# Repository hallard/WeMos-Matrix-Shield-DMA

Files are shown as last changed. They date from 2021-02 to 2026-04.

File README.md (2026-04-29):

# ESP32 D1 Mini D1 RGB Matrix Shield 

This shield is the following of this [project](https://github.com/hallard/WeMos-Matrix-Shield) but I created a new repo since the board is different, wiring also and even the library used to drive Matrix.

This board is used to simplify ESP32 connectivity with a nice matric RGB led. This idea came from excellent project called [Morphing Digital Clock][3] done by [HariFun][1] Instructable. But with this library and current code I got some issues with mutitasking, and using same time the awesome Async libraries ([Web Server](https://github.com/me-no-dev/ESPAsyncWebServer) and [MQTT](https://github.com/marvinroger/async-mqtt-client)) getting very ofther in reboot and board reset. I don't blame anyone, the library used was just to drive matrix, it's always complicated mixing some libraries sometimes especially ones with hardware intensive related suff, IRQ's and TCP.

This was until [@mrfaptastic](https://github.com/mrfaptastic/ESP32-HUB75-MatrixPanel-I2S-DMA) released the DMA version wich is far less CPU intensive. I tested this one with Async Web Server, Async MQTT and OTA without any issue. You can participate to the @vortigont started discussion [here](https://github.com/mrfaptastic/ESP32-HUB75-MatrixPanel-I2S-DMA/discussions/96) Thanks to github for this new feature.

See it in action, nice isn't it?



This breakout has just few minimal features.

**New in Version V1.9**

- Touchpad 9 (T9) used and wired to GPIO32
- Exposed (top right corner) GPIO0 instead of GPIO32
- Reversed I2C connector order, because all I2C wiring have components on top except Luminosity TSL2561 BH1750, now fixed
- I2C connector order have drilled holes to match sensor plug, no need to solder to fix or swap sensor type. Just press it to fit into holes
- Added another pin close to I2C connector connected to GPIO34 (for using sensor IRQ pin for example)
- Major re-routing to fix issues

**New in Version V1.8a**

- **this PCB version does not work, please don't use it**
- Added C1, C2, C3 footprints. It's to add capacitor to poor 3.3V VOut of esp32 on board regulator. This one is not output filtered enough resulting sometimes with brownout reset loop. Now you can plug radial or 1 (or 2) SMD 0805 in parallel

**New in DMA Version V1.8**

- **this PCB version does not work, please don't use it**
- Removed ESP8266 compatibility, since DMA need more GPIO it's now exclusive to ESP32 boards with WeMos Mini D1 wiring called ESP32 Mini Kit or ESP32 Wemos, or ESP32 MH-ET Live such as this [banggood model](https://www.banggood.com/Wemos-D1-Mini-ESP32-ESP-32-WiFiBluetooth-Internet-Of-Things-Development-Board-Based-ESP8266-p-1205854.html) or this [aliexpress](https://www.aliexpress.com/item/MH-ET-LIVE-D1-mini-ESP32-ESP-32-WiFi-Bluetooth-Internet-of-Things-development-board-based/32815530502.html). But you can find a lot also on ebay, not a problem.
- PCB board has been extented to fit this ESP32 Mini module .
- LDR to dynamically change brightness according to ambiant light
- I2C connectors as header and Groove to plug a bunch of sensors
- Added one touch pad button
- No need to wire back the shield to HUB75 output of the Matrix Panel

Please check wiring and picture before ordering, should looks like something like that:

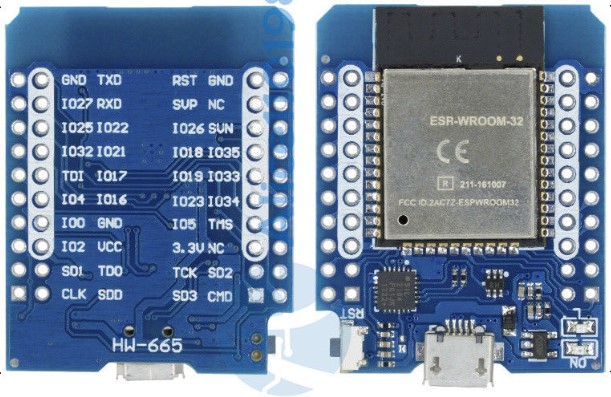
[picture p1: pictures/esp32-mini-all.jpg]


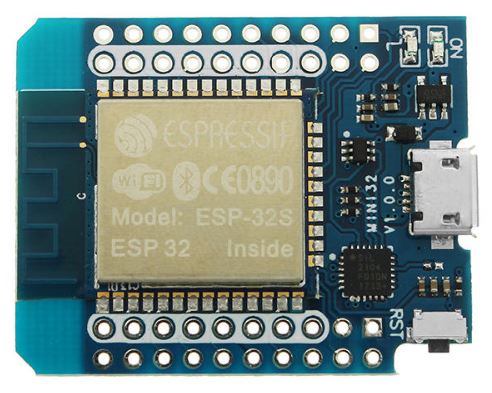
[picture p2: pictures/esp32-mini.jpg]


**V1.9 are fully tested and working**.

**V1.8 and V1.8a boards are not working** I've been too confident, this is the 1st time I need to throw out all boards. Reason is that both ESP32 headers the ones side by side were reversed (on each side).
I mean the 1st was the 2nd and vice versa), So as you can imagine nothing was unable to works, even flashing ESP32.

# Detailed Description

Look at the schematics for more informations.

# Schematic  

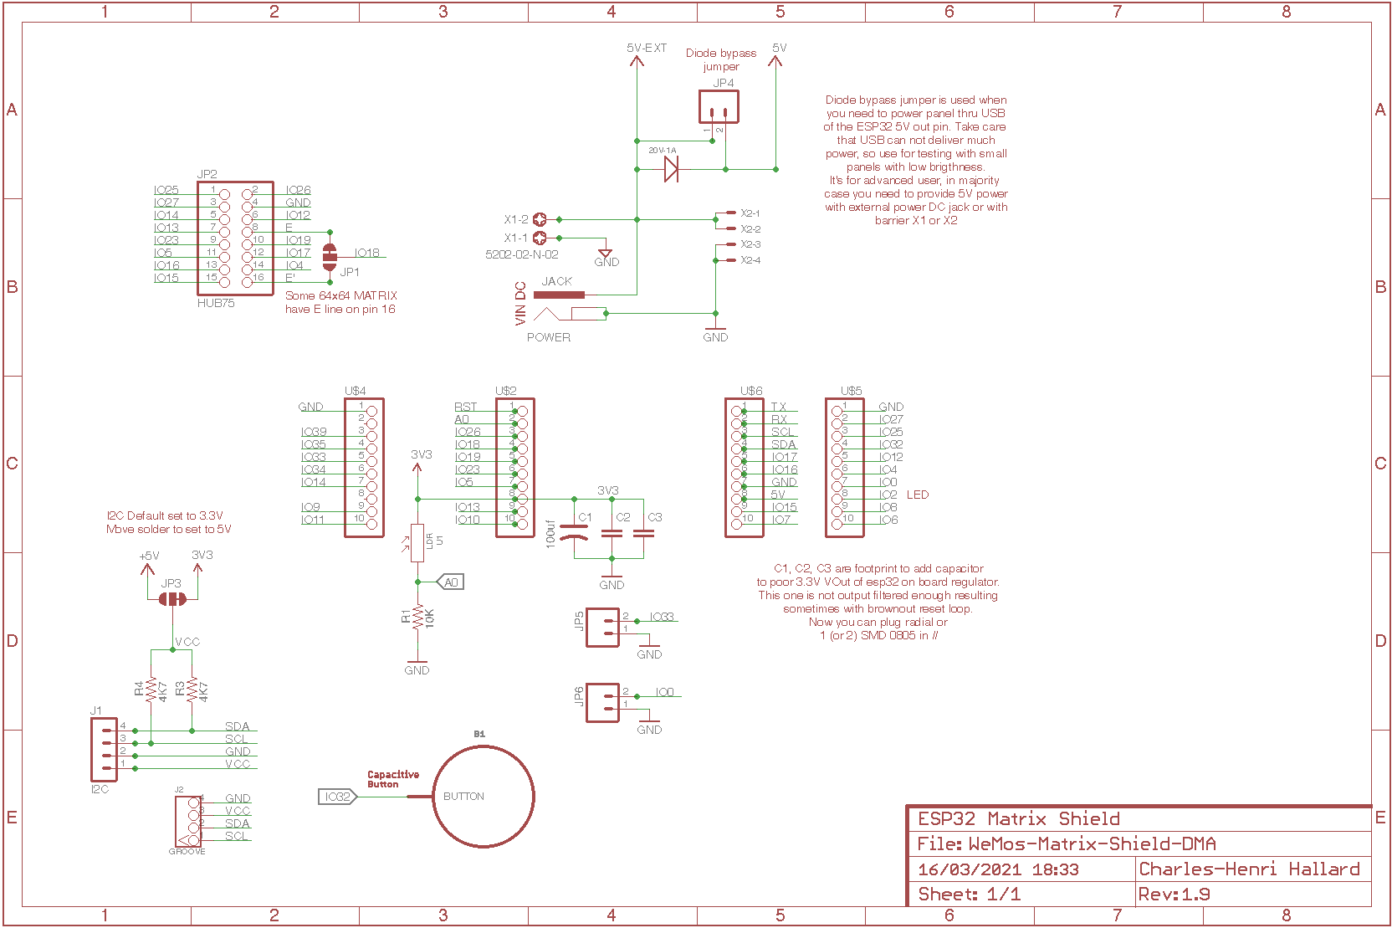
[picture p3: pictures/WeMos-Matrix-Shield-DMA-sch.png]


# Boards  

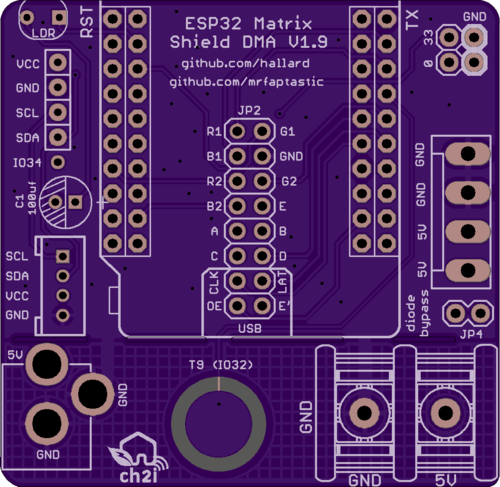
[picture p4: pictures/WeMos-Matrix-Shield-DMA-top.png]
Top
&nbsp;
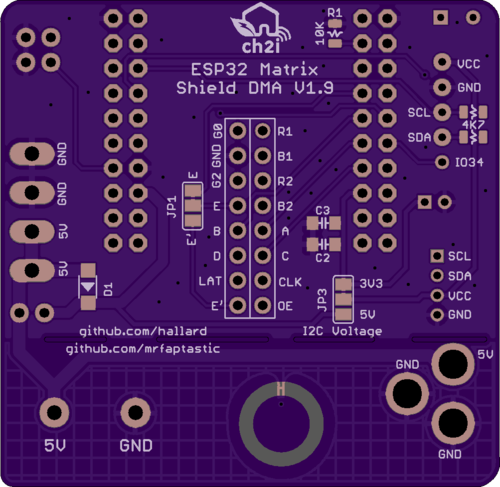
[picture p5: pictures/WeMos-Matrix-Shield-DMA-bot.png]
Bottom


~~You can order PCBs of this board at [PCBs.io)(ttps://www.pcbs.io/)~~

 ~~PCBs.io give me some reward when you order my designed boards from their site. This is pretty good, because I can use these rewards to create and design new boards and order boards for a discounted price, so if you don't care about PCB manufacturer please use PCBs.io.~~

Looks like PCBs.io is gone, I do not have any rewards from PCBs.io since August 2020 and my free order placed after are still not received, so my guess they are not on business anymore and my $1000 rewards are not usable anymore, too bad.

So you can order the board on [oshpark](https://oshpark.com) or submit gerbers.zip file to any PCB manufacturer of your choice.

- [V1.9](https://oshpark.com/shared_projects/gCeBFgxd)

It's a pitty after several discuss with OSHPark that I can't have any rewards for each people ordering my boards, this would allow me to order free PCB for shared projects and create new ones. For information my shared boards generated a total of **$285 162.00** orders at PCBs.io in 4 years, not bad at all :-)

Hoping one day OSHparks will thanks me giving them this market. 

# Firmware

I suggest you to look at the awesome [examples](https://github.com/mrfaptastic/ESP32-HUB75-MatrixPanel-I2S-DMA/tree/master/examplesk) located in the [library](https://github.com/mrfaptastic/ESP32-HUB75-MatrixPanel-I2S-DMA) driving the Matrix Panel.
 
# Assembled boards

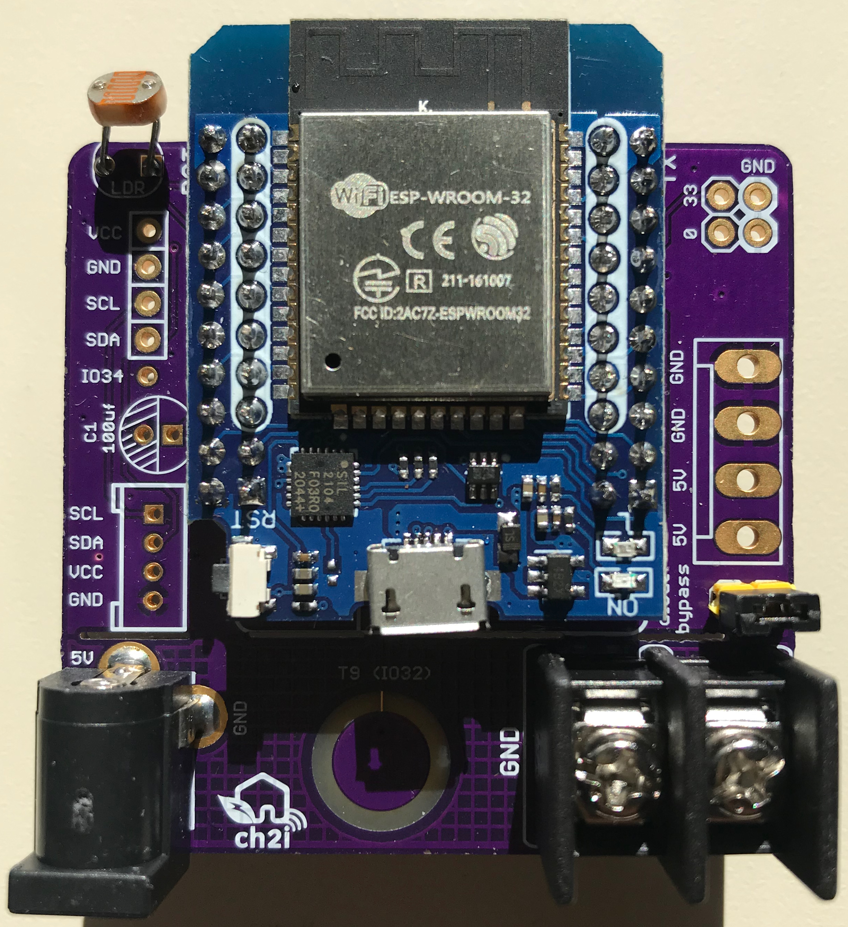
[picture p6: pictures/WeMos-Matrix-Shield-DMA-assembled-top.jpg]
Assembled Top
&nbsp;
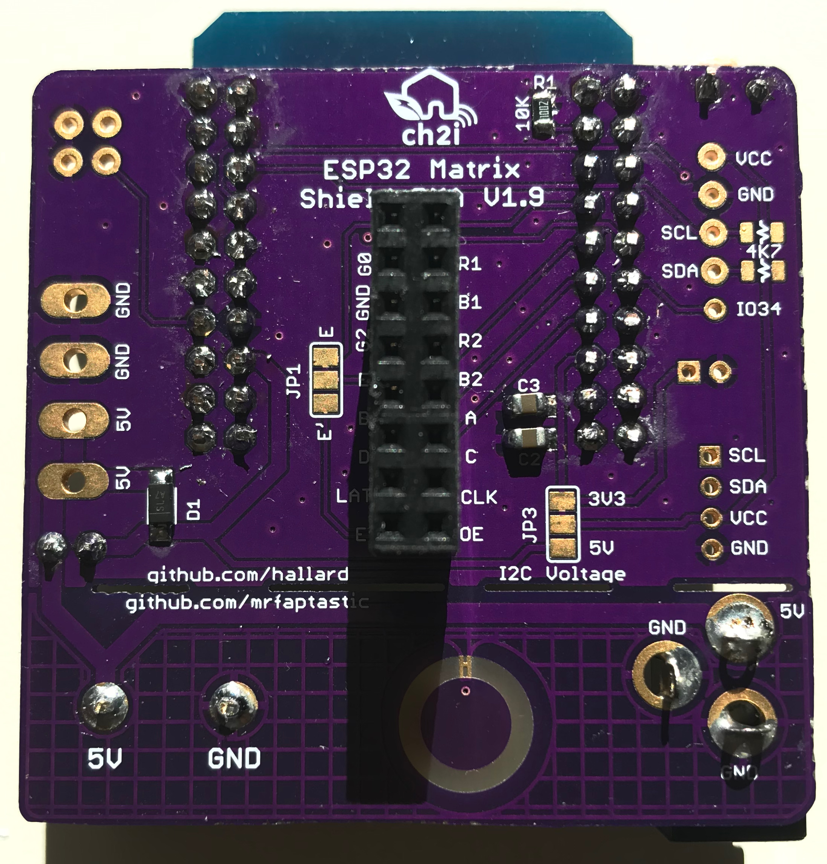
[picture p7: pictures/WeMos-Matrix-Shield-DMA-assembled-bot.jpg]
Assembled Bottom


# BOM

Nothing fancy, just some headers and 2 differents power conector (choose the one you prefer) :

 - 10K 0805 resistor for LDR
 - Any LDR PhotoCell 5528
 - I2C 4.7K resistor 0805 if needed, default I2C set to 3.3V use JP3 if you prefer 5V
 - For better stability C1 100uF 16V electrolytic, or C2 100uF 0805, or C2+C3 47uF 0805
 - Diode can be any Schottky diode barrier and is not mandatory (if not close JP4 jumper)
 - Ebay search for "DC Power Jack Barrel PCB Mount"
 - 7.62mm barrier terminal block [example](https://ebyelectro.com/terminal-block-product-info.asp?ProductID=333)
 - Ebay search for "2X8 Pin 2.54mm Double Row Female Header" or polulu product #1028, you can also use twice 1x8 pin female or even twice 2x4 pins female, plenty of option for this one
 
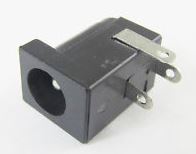
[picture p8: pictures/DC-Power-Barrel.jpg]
 
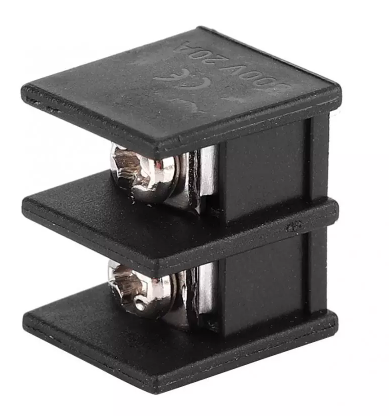
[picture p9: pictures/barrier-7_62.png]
 
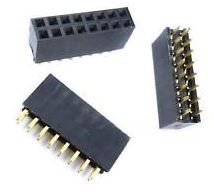
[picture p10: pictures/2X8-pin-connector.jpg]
 

# License

   

This work is licensed under a [Creative Commons Attribution-NonCommercial-ShareAlike 4.0 International License](https://creativecommons.org/licenses/by-nc-sa/4.0/)    

# Misc

See news and other projects on my [blog][2] 

Thanks to @mrfaptastic, @vortigont, @me-no-dev and all other I may forgot.
 
[1]: https://www.instructables.com/member/HariFun/
[2]: https://hallard.me
[3]: https://www.instructables.com/id/Morphing-Digital-Clock/
[4]: https://PCBs.io/share/

[20]: https://wiki.wemos.cc/products:d1:d1_mini_lite
[21]: https://wiki.wemos.cc/products:d1:d1_mini
[22]: https://wiki.wemos.cc/products:d1:d1_mini_pro

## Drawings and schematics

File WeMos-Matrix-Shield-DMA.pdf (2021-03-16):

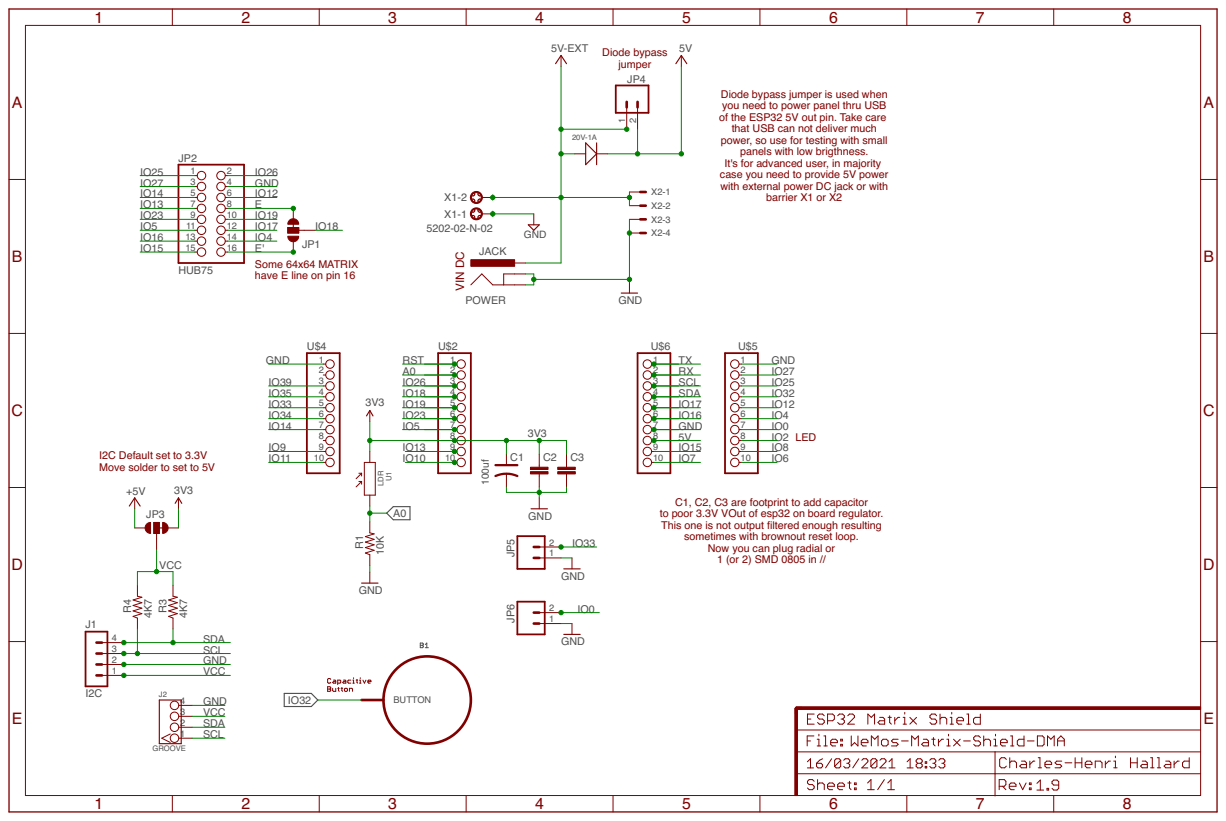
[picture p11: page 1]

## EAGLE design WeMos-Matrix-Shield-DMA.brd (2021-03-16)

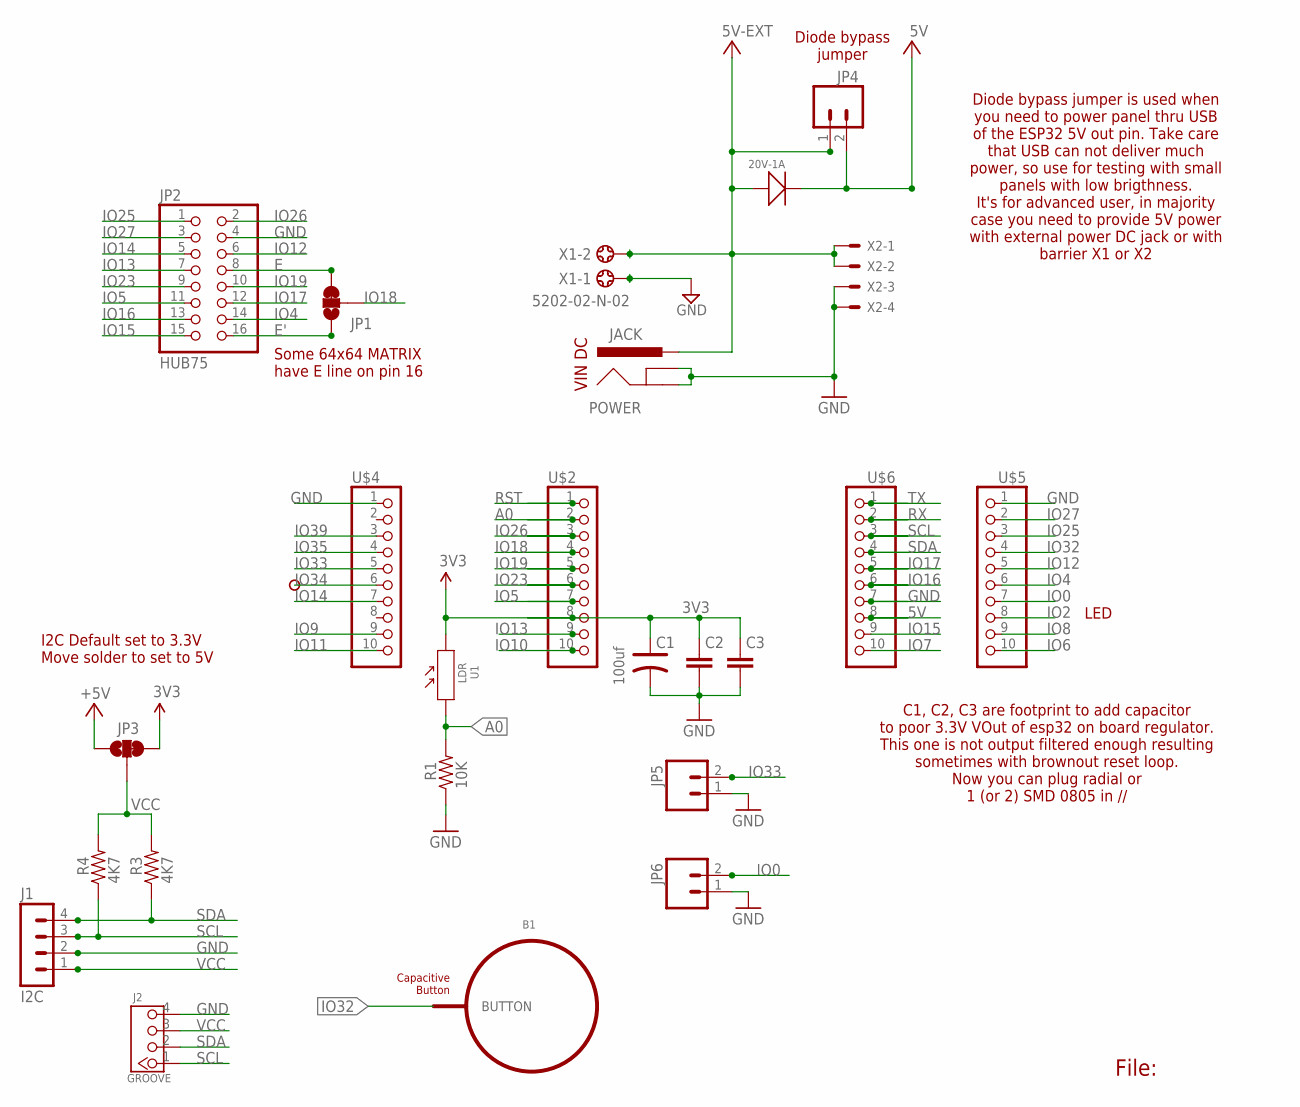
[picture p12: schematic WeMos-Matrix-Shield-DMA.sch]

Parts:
B1: BUTTON_PASSIVE6MM; BUTTON_PASSIVE_6MM
C1: 100uf; PC-D5.3MM
C2, C3: CAP0805-CAP-LARGEPADS; 0805-CAP-LARGEPADS
D3: 20V-1A; SOD-123
J1: I2C; 1X04_LOCK_HOLE
J2: GROOVE; 2.0_1X4
JACK: POWER; POWER_JACK_PTH
JP1, JP3: JUMPER-PAD-3-2OF3_NC_BY_TRACE_LARGE; PAD-JUMPER-3-2OF3_NC_BY_TRACE_YES_SILK_LARGE
JP2: HUB75; 2X08
JP4, JP5, JP6: M02; 1X02
P2: PADSMALL; PAD-SMALL
R1: 10K; 0805-RES
R3, R4: 4K7; 0805-RES
U1: LDR; SNR2-3.0
U$2, U$4, U$5, U$6: PINHD-1X10; 1X10-BIG
X1: 5202-02-N-02
X2: KK-156-4

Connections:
3V3: C1.+, C2.1, C3.1, JP3.3, U1.2, U$2.8
5V: D3.-, JP3.1, JP4.2, U$6.8
5V-EXT: D3.+, JACK.PWR, JP4.1, X1.2, X2.1, X2.2
A0: R1.2, U1.1, U$2.2
E: JP1.3, JP2.8
E': JP1.1, JP2.16
GND: C1.-, C2.2, C3.2, J1.2, J2.4, JACK.GND, JACK.GNDBREAK, JP2.4, JP5.1, JP6.1, R1.1, U$4.1, U$5.1, U$6.7, X1.1, X2.3, X2.4
IO0: JP6.2, U$5.7
IO2: U$5.8
IO4: JP2.14, U$5.6
IO5: JP2.11, U$2.7
IO6: U$5.10
IO7: U$6.10
IO8: U$5.9
IO9: U$4.9
IO10: U$2.10
IO11: U$4.10
IO12: JP2.6, U$5.5
IO13: JP2.7, U$2.9
IO14: JP2.5, U$4.7
IO15: JP2.15, U$6.9
IO16: JP2.13, U$6.6
IO17: JP2.12, U$6.5
IO18: JP1.2, U$2.4
IO19: JP2.10, U$2.5
IO23: JP2.9, U$2.6
IO25: JP2.1, U$5.3
IO26: JP2.2, U$2.3
IO27: JP2.3, U$5.2
IO32: B1.BUTTON, U$5.4
IO33: JP5.2, U$4.5
IO34: P2.1, U$4.6
IO35: U$4.4
IO39: U$4.3
RST: U$2.1
RX: U$6.2
SCL: J1.3, J2.1, R4.1, U$6.3
SDA: J1.4, J2.2, R3.1, U$6.4
TX: U$6.1
VCC: J1.1, J2.3, JP3.2, R3.2, R4.2

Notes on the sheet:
File:
VIN DC
I2C Default set to 3.3V Move solder to set to 5V
Some 64x64 MATRIX have E line on pin 16
Diode bypass jumper
Diode bypass jumper is used when you need to power panel thru USB of the ESP32 5V out pin. Take care that USB can not deliver much power, so use for testing with small panels with low brigthness. It's for advanced user, in majority case you need to provide 5V power with external power DC jack or wi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
C1, C2, C3 are footprint to add capacitor to poor 3.3V VOut of esp32 on board regulator. This one is not output filtered enough resulting sometimes with brownout reset loop. Now you can plug radial or 1 (or 2) SMD 0805 in //
LED

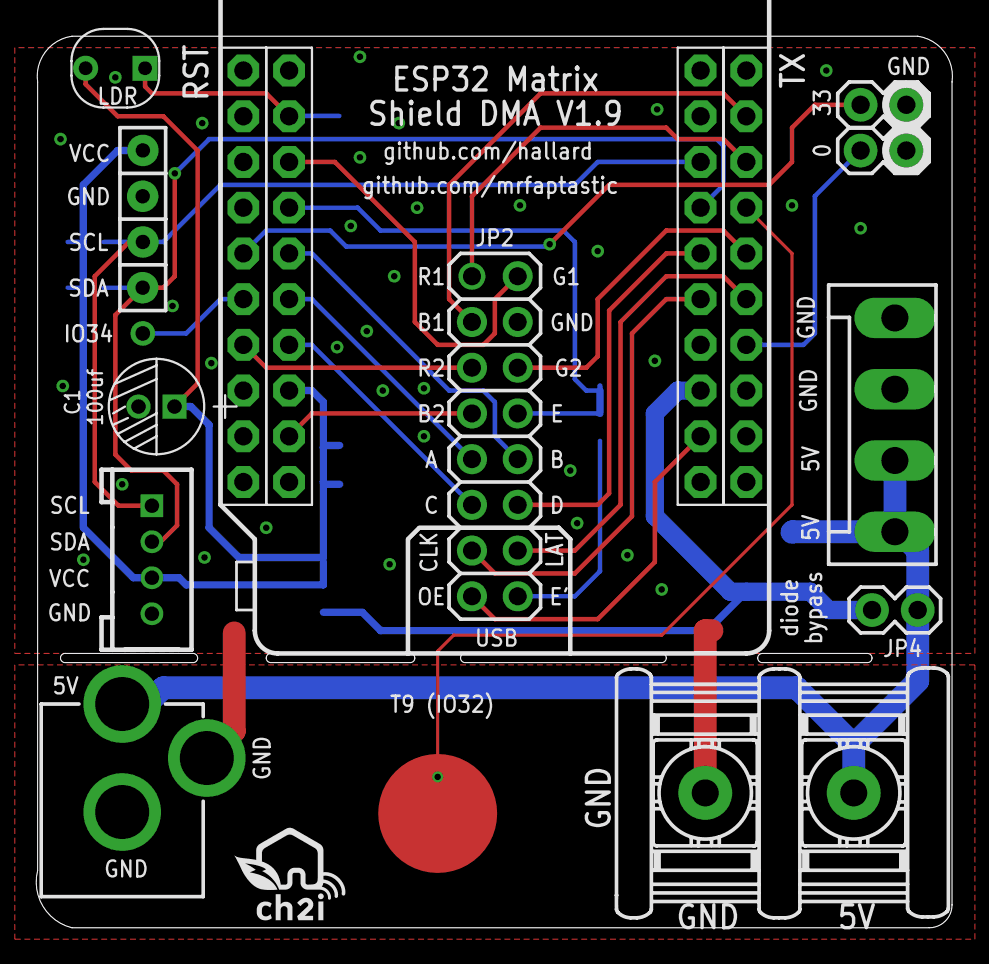
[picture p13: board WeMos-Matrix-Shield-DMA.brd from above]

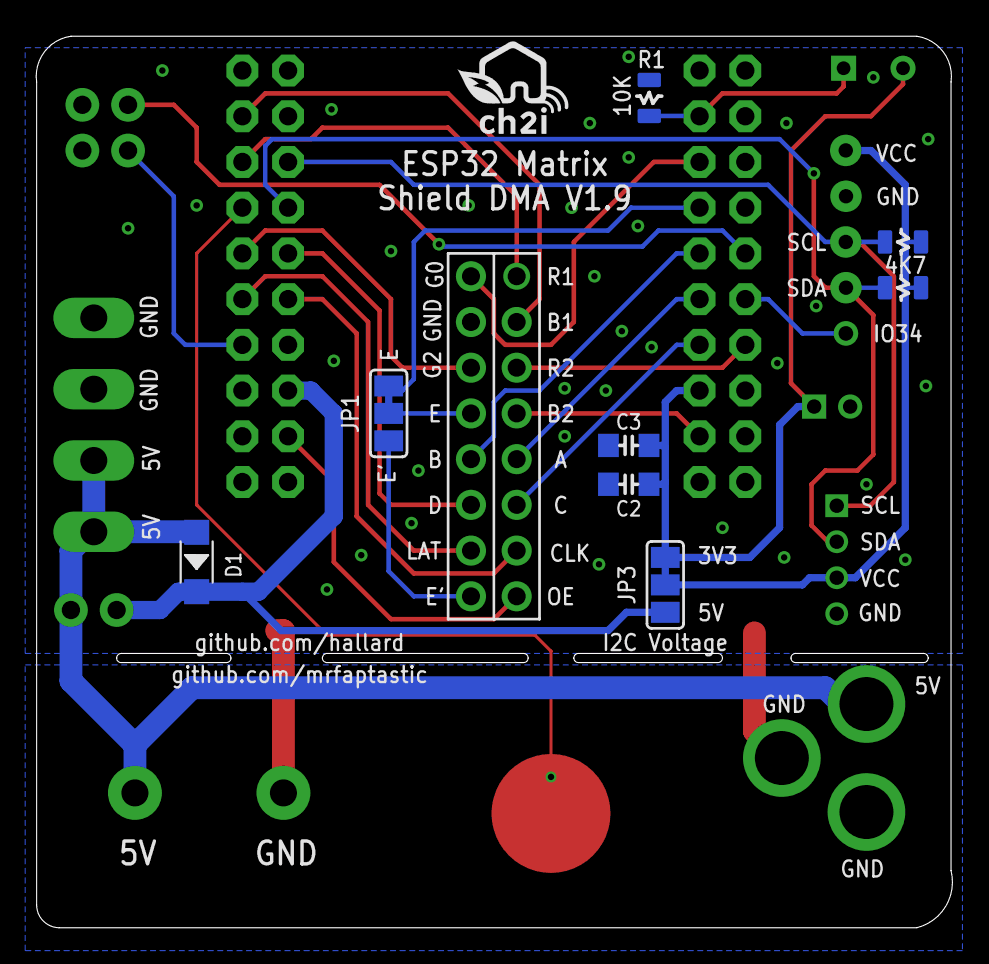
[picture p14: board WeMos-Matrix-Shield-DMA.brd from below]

Board: 2 copper layers, 50.9 x 49.5 mm, 27 parts (9 on the bottom side), 28 nets.

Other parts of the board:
U$7, U$8: LOGO_C2I_015

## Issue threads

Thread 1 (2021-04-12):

Small corrections, and a couple of questions

bogd, 2021-04-12:
First of all, thank you for the great work you did on this - it was the only open-source PCB that I could find for the I2S library! Your work is truly appreciated!!

A few (very small) things you may want to fix in the next version:
- the silkscreen on the back still shows a G0 (on the front it has G1 for the same pin)
- on the silkscreen, you have links to your and mrfaptastic's github pages - unfortunately, the links partly overlap with the cutouts in the board, so they can be difficult to read

Also, a couple of questions for you:
- what type of screw terminal are you using? Because the ones that I could source (such as [this one](https://www.aliexpress.com/item/4000600315390.html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,searchweb201602_,searchweb201603_) ) all have the pins offset from the center - while the footprint on your board has the pins fully centered
[ Edit - found them! Thanks to the link you posted, I managed to find them [here](https://www.aliexpress.com/item/32359125431.html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,searchweb201602_,searchweb201603_). They just seem to be a... rare breed, compared to the asymmetrical ones :) )
- what type of connector should I use for the 5V/GND connector on the side of the board? I originally assumed it would be something like [this](https://www.aliexpress.com/item/1005002157208121.html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,searchweb201602_,searchweb201603_), but it seems to have different pin spacing
[ Edit - found this one as well, by looking at the schematic. It is a KK-156-4 connector. I would guess [this one](https://eu.mouser.com/ProductDetail/Molex/76650-0102?qs=5NHWMpvrJ2C2NvuJzvI7ew%3D%3D)? ]
- did I understand the T9/IO32 pad correctly? Is it designed to work as a touch sensor? If so, can you tell us how  to read it from code?
[ Edit - found this one as well :) . The ESP32 has dedicated touch pins - T9 being "Touch 9". A nice tutorial on using them is [here](https://randomnerdtutorials.com/esp32-touch-pins-arduino-ide/)

So my questions have been answered - however, I will leave them here, in case you may want to add some additional info to the documentation for the board (such as the touchpin tutorial linked above)
].

Once again, a big _thank you_ for your work on this!!

hallard, 2021-08-15:
@bogd Nice you found your answers, sure sometimes link on aliexpress change and product also so it's complicated to keep them up to date.

Thank you for sharing your answer and links.

Have fun

bogd, 2021-08-16:
@hallard - thank you once again. I truly appreciate all the work you put into this, and the fact that you open sourced the project. In fact, your work gave me the courage to start building my own version of the matrix shield (and, of course, I open sourced that as well - share and share alike :) ).

I will close this issue now, since all my questions have been answered. Once again, a big thank you!!

Closed 2021-08-16.

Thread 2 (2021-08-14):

Source for boards

lanman1, 2021-08-14:
You can try using https://www.pcbway.com/   I have used them before, they are inexpensive and have a rewards system.  The quality is excellent and I usually get a free gift when I order boards.  10 boards are $15 shipped to the US.

Hope this helps and thank you for your work.

lanman1, 2021-08-14:
one thing I notice when I upload the Gerbers, it looks like pads and not thru-hole.
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

hallard, 2021-08-15:
That is strange, uploaded zip file to oshpark and looks nice

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

Anyway last time I tried pcbway for an already done board by someone else it told me I needed to wait until manual verification from pcbway team, so I gave up, may be need to try again.

lanman1, 2021-08-15:
Yeah, there usually i a manual verification where a human looks at it to make sure it is ok.  Usually takes less than a day.  I've ordered from them probably 10 times but maybe that aren't as good for EU.  I'll probably go ahead and place an order and report back, 10 boards through them are cheaper than the 3 for Oshpark.  I could be doing something wrong tho  :)

bogd, 2021-08-16:
@lanman1 - I used jlcpcb, and their system did show the drill holes correctly. And, indeed, when I received the boards, they did have the correct holes drilled.

I have also uploaded the current version of the gerbers.zip in this repo to their system, and once again it shows the drill holes correctly:
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

However, the exact same file viewed in pcbway's viewer does not show the drill holes:
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

It looks like a limitation of their gerbers viewer.... (and an ugly one, at that :) )

lanman1, 2021-08-18:
I'll give jlcpcb a shot, thanks!

vortigont, 2021-08-19:
I've got my batch from cnospcb and those are just fine. Thanks to @hallard for making his work public, it is much more comfortable to use shields than messing with dangling jump wires :)

M10CUBE, 2021-08-20:
Thanks @hallard for the grate V1.9 design. I got my lot of PCBs. Now trying to lit the RGB display but having problems with the display (16x32) found in my lab with the HUB75 connector. It has only A and B signal rows with C and grounded.
So I see confusing images. While I am waiting a new RGB from China is any example to guide me how to position text and display simple numbers or text? The examples do not have similar software.
The RGB will be used to display environmental data for our project
https://hackaday.io/project/171770-m10cube
Thanks a lot

EclipseBoom, 2023-03-29:
Here is a tip I swiped from SmartMatrix for Teensy.  If you use a 20-way female dual row connector for the panel and clip off the extra 2 pins on each side, the connector will fit snugly into the IDC cable plug on the panel with no chance to get the connector offset like it can with a 16-way.

Also, if you don't put female headers on the Wemos HUB75 board it is much lower profile and can almost fit within the plastic frames of the panel itself.  Just solder the ESP32 unit onto the HUB75 interface and clip off the extra long pins on one side.  Can't come loose that way either.

Finally I like to use the JST/Molex in a Right-Angle connector to supply 5V to the ESP32 HUB75 board.  This allows the typical 2-plug panel power cable to connect one to the panel and the second to the HUB board leaving the fork terminals for the power supply.  Nice and clean with no extra cables required for a single panel configuration.

Also not really an issue.  There is not really any way I can use the touch button and I don't need the LDR so those GPIO could be used for other things.  I would like to see the extra GPIO gathered into a header to connect remote buttons and controls and so forth away from behind the panel.

M10CUBE, 2023-03-30:
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
@EclipseBoom can you be specific on that? do you have pictures?
For mine (first image)  I choose to use long 2x20 socket for the HUB75 connector and for the ESP32 to sit on. I like to see yours but with images if you can find some time. That will help to integrate your ideas .

Now the P3-6432-21-16S-D1 RGB display I got is working fine (first image)
The problem is with a second P4 RGB display the S-P4-3020-A3 display (second image) I have and is not working. Just flashing in a strange way.
This is a similar one:
https://www.aliexpress.com/i/32514844235.html
It has the TC7258EN (8-channel LED display line scanning blanking control driver) and MBI5124 (16 Channel Constant Current LED Driver).
Any idea who to make that work? Is the same driver?
I will appreciate any ideas.
Thanks a lot in advance
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

EclipseBoom, 2023-03-30:
Here is my low-profile configuration.  I mount the panels to a 12mm high Aluminum channel and this fits under that.
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

M10CUBE, 2023-03-30:
Ok  I see your idea. Looks nice. Your panels must  be different than mine.
Thank you

Στις Πέμ, 30 Μαρ 2023, 20:05 ο χρήστης EclipseBoom ***@***.***>
έγραψε:

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

Yaxit, 2023-05-04:
@EclipseBoom could you point me to the connector you used for the screen power (white one with 2 5V and 2GND)? I cannot find the one I want :D

EclipseBoom, 2023-05-04:
That connector is JST-VH series.  S4P-VH(LF)(SN)  Bought at Digikey.

There is a Molex one that fits too but it has little nubs on the bottom of the plastic that need to be cut off and more expensive.

Yaxit, 2023-05-05:
Thank you. Would be nice to have it in the board BOM along the rest.

crazy-weasel, 2023-07-19:
Hi, I ordered a few v1.9 PCBs via jlcpcp and now I have more than I need. :)

If anyone needs some, I could send them to you. Shipping within the EU should be reasonable if you want only one or two (or three..)

glen020, 2024-02-25:
Hey, Got my pcb's working flawlessly thank you!
Question, what part numbers do you have for the Power connectors? I cant seem to find the 4 pin ones or the exact ones @EclipseBoom

EclipseBoom, 2024-02-26:
> Hey, Got my pcb's working flawlessly thank you! Question, what part numbers do you have for the Power connectors? I cant seem to find the 4 pin ones or the exact ones @EclipseBoom

JST VH series
From Digikey:  Mfr # S4P-VH
Digikey #: 455-S4P-VH-ND

I like these because they work with the power connector cable that comes with the panels.  Just use the fork end to the P.S. and the two VH connectors go one to the panel and one to the ESP32 shield.  Super clean.

EclipseBoom, 2024-03-02:
@hallard I'm prepared to get these PCBs fabricated in quantity and continuously stock them through my robotpower.com business for easy access by everyone without needing to hassle with the Gerber files or getting 3x minimum from OSH Park or waiting 2-3 weeks for the PCB panel to process.  I would sell them for approximately the cost of an OSH order each i.e. ~$6.20 USD.  But I would need to charge a little for handling plus postage of course.  I'm thinking about $10 USD delivered for 1x bare PCB inside the US would cover it.   However the CC BY-NC license doesn't seem compatible with this scheme.  I think I would need the CC BY-ND or SA license

I would also like to offer kits and  to assemble them for makers who don't want to source parts and/or do soldering but just want to get to making their cool project.  This would cost extra of course for the labor.

I sent and email to the Github owner address but no reply so far.

hallard, 2024-03-03:
@EclipseBoom, glad to see you would like to provide it in you shop.
I'm the owner of this github repo but did not received any email, would you mind try to send it again so we can continue this discussion in PM please?
Thanks
Charles

EclipseBoom, 2024-03-03:
Sent email to hallard04@free.fr which is your github home page email contact address.  Is there a different one?

You can contact me at chris ___at____ robotpower.com

EclipseBoom, 2024-03-04:
resent email to above address

hallard, 2024-03-05:
Can't receive your email, just wrote to your mail from another one

EclipseBoom, 2025-02-22:
The bare PCB version of my v1.9a fork is now available on Tindie.  https://www.tindie.com/products/cb_robotpower/hub75-rgb-led-matrix-shield-for-esp32-pcb/  The first product is a panel of 3x of these PCBs for $19.55 USD.  This is the same cost as OSHPark.

These are identical to the v1.9 version here except for some added connectors and GPIO contacts.

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

A kit of parts and fully-assembled units will be available as soon as I can secure a reliable supply of parts.  Charles-Henri will receive a royalty on kits and assembled units.

These ship next day from stock.  We intend to keep these in stock at all times so you can order without the OSHPark waiting time.

Free Shipping for USA customers.  USPS Priority mail to your national Post for worldwide customers.

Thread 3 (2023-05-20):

ESP32-S3 Varient

netmindz, 2023-05-20:
Looks like a great hardware project but the code I would wish to run on it requires the newer S3 version of the chip.

Or do you know of a pin compatible S3 board?

netmindz, 2023-10-25:
Still interested in this

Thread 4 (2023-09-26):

Uploading issue

netdudeuk, 2023-09-26:
Hi

I ordered your latest board thanks.  All soldering looks ok but even with the board not plugged into the matrix, I get the following error message when using the Arduino IDE -

_Sketch uses 264501 bytes (20%) of program storage space. Maximum is 1310720 bytes.
Global variables use 21952 bytes (6%) of dynamic memory, leaving 305728 bytes for local variables. Maximum is 327680 bytes.
esptool.py v4.5.1
Serial port COM9
Connecting.....................................An error occurred while uploading the sketch
.

A fatal error occurred: Failed to connect to ESP32: Download mode successfully detected, but getting no sync reply: The serial TX path seems to be down.
For troubleshooting steps visit: https://docs.espressif.com/projects/esptool/en/latest/troubleshooting.html_

I don't get this issue if I move the USB cable into a new ESP32-WROOM32 board.

I just have the USB cable connected.  Am I using the board correctly ?

Any ideas please ?

Thanks

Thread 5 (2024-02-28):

Only Red

jrlambs, 2024-02-28:
Hi, I'm fairly certain this is not an issue with this board, but I'm having an issue with some boards I ordered.  I'm using a wemos esp32 mini like you are.. confirmed pinouts are the same.  I'm having the same issue with everything wired to your board as I was when I was just hooking things up with dupont cables.... which is that everything is red!  I can only get VERY faint green and if there's any blue at all it is almost invisible.   If I print something in white it basically just displays in red since it's really showing blue or green colors.

At the moment I only have the esp32 and female connector on the bottom attached to the board.  it looks like you have other things hooked up.. but I'm not an engineer and don't understand the schematic.   I was curious if you'd recommend hooking anything else up for troubleshooting. perhaps c1 c2? or something along those lines?

jrlambs, 2024-02-28:
I'm configuring the library with these values:
#define R1_PIN  25
#define B1_PIN  27
#define R2_PIN  14
#define B2_PIN  13
#define A_PIN   23
#define C_PIN   5
#define CLK_PIN 16
#define OE_PIN  15

#define G1_PIN  26
#define G2_PIN  12
#define B_PIN   19
#define D_PIN   17
#define E_PIN   -1
#define LAT_PIN 4

jrlambs, 2024-02-29:
Disregard,my power supply was dead and that was the ultimate cause of my issue

Closed 2024-02-29.

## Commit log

2021-02-27 Added gerber files
    [WeMos-Matrix-Shield-DMA.drills.xln]
2021-02-28 bump to v1.8a
    [WeMos-Matrix-Shield-DMA.brd, WeMos-Matrix-Shield-DMA.sch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]
2021-02-28 Changed boards images size
2021-03-16 Updated to V1.9
    [WeMos-Matrix-Shield-DMA.GBL, WeMos-Matrix-Shield-DMA.GBO, WeMos-Matrix-Shield-DMA.GBP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]
2026-04-29 Switch to CC BY-NC-SA 4.0 license, add LICENSE file

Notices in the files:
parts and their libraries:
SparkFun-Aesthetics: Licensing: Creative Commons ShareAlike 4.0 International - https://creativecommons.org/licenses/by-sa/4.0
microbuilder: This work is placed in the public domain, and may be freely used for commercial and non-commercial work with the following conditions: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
